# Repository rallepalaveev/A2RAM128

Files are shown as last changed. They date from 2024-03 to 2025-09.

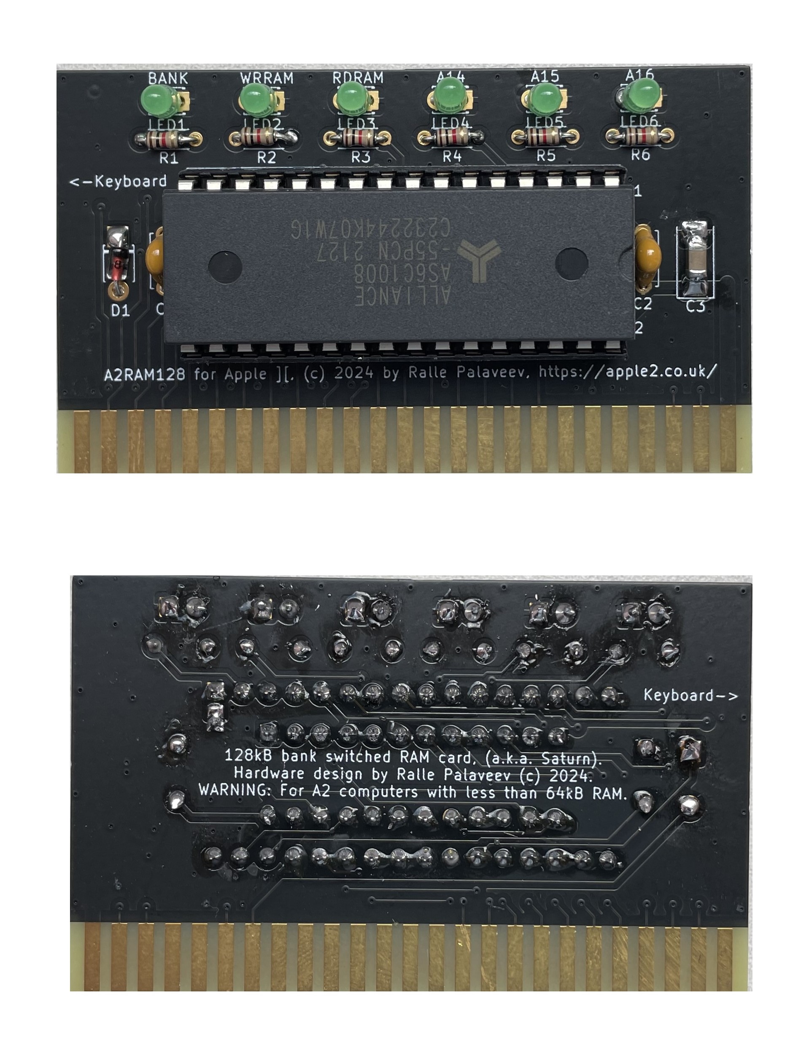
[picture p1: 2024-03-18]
A2RAM128.jpg

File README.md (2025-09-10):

# A2RAM128

This is an expansion 128kB RAM card for Apple2 computers, which uses the the upper 16kB, which are mapped to the 12kB ROM space $D000-$FFFF.

The card uses the standard 50-pin slots, and adds 8 banks of 16kB - a total of 128kB, based on modern chips like SRAM, and not needing to have any additional cables to connect to the motherboard.

This project is based on one 128kB SRAM chip and one PLD for logic.

The logic of the card follows the design recommendations of the Saturn cards:

There are 8 x 16kB banks of the following organization:
* Two sub-banks A and B of 4kB are mapped to $D000-$DFFF
* One sub-bank of 8kB is mapped to $E000-$FFFF

Bank-switched RAM soft switches:

| Address | Symbolic Name | Bank | Read From | Write to RAM? |
|:---|:---|:-----|:---|:---|
|$C0N0|READBSR2|2|RAM|No|
|$C0N1|WRITEBSR2|2|ROM|Yes*|
|$C0N2|OFFBSR2|2|ROM|No|
|$C0N3|RDWRBSR2|2|RAM|Yes*|
|$C0N8|READBSR1|1|RAM|No|
|$C0N9|WRITEBSR1|1|ROM|Yes*|
|$C0NA|OFFBSR1|1|ROM|No|
|$C0NB|RDWRBSR1|1|RAM|Yes*|

| Address | Function |
|:---|:---|
|$C0N4|Select Bank 1|
|$C0N5|Select Bank 2|
|$C0N6|Select Bank 3|
|$C0N7|Select Bank 4|
|$C0NC|Select Bank 5|
|$C0ND|Select Bank 6|
|$C0NE|Select Bank 7|
|$C0NF|Select Bank 8|

N is the Slot Number + 8.

Operation:

The card houses the 3 soft-switches above which upon reset are configured in the default configuration:

* Sub-bank A is selected
* ROM is readable
* RAM is writeable (v2.0 RAM is not writable)

A test to be made for quick check of functionality:

]CALL-151           # Enter monitor

*C0N1               # Start activation of RAM for writing (v2 only)

*C0N1               # Activation of RAM for writing

*F800<F800.FFFFM    # Copy monitor to RAM

*C0N3               # Set RAM for reading

This sequence should not lead to the computer freezing with a responce "$C0N3-", because the monitor is copied to the RAM and continues to work from RAM.

The benefit of the card is that programs which require 64kB of RAM or more can be used - primarily ProDOS. It works from any 50-pin slot with no additional cabling - P&P, however some programs expect that the card is in slot #0, so this is the recommended use.

V2.0 was created to fullfill the requrements by the Saturn cards to activate the card for writing by two succecutive calls to C0N1. It is advisable that this version is used.

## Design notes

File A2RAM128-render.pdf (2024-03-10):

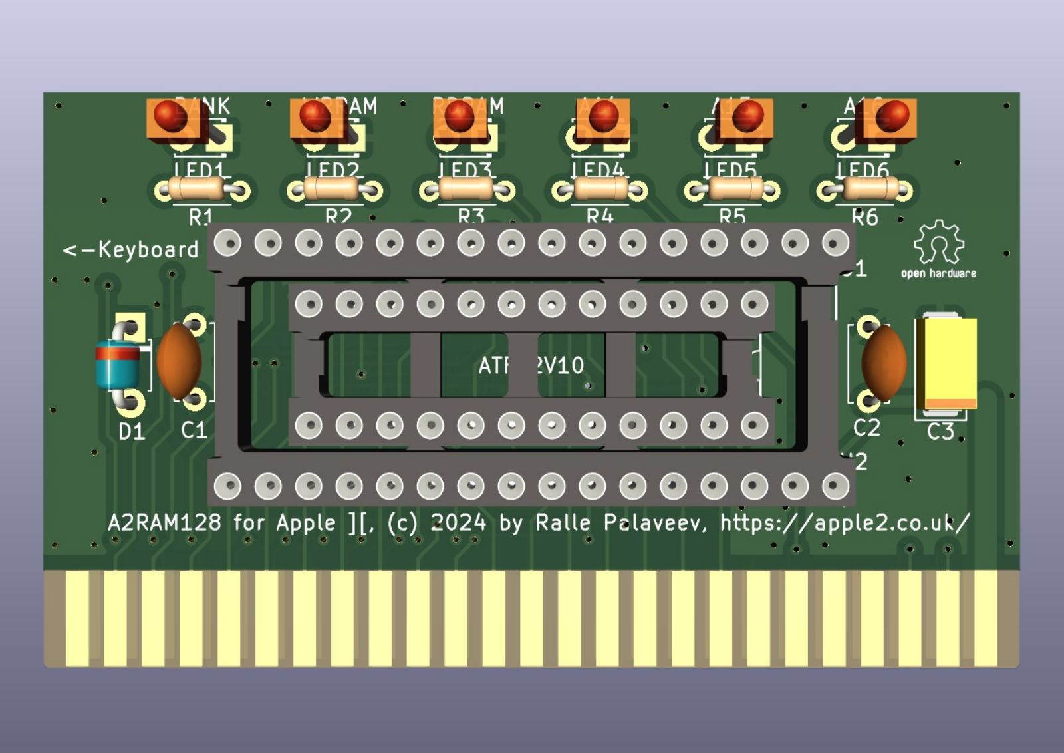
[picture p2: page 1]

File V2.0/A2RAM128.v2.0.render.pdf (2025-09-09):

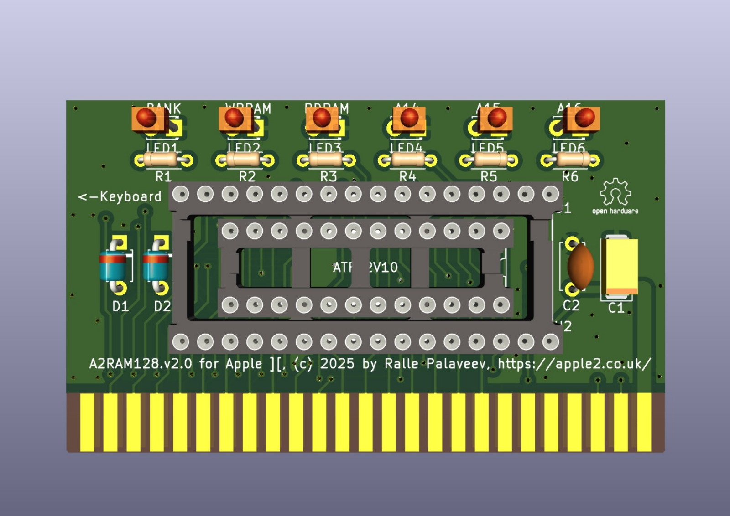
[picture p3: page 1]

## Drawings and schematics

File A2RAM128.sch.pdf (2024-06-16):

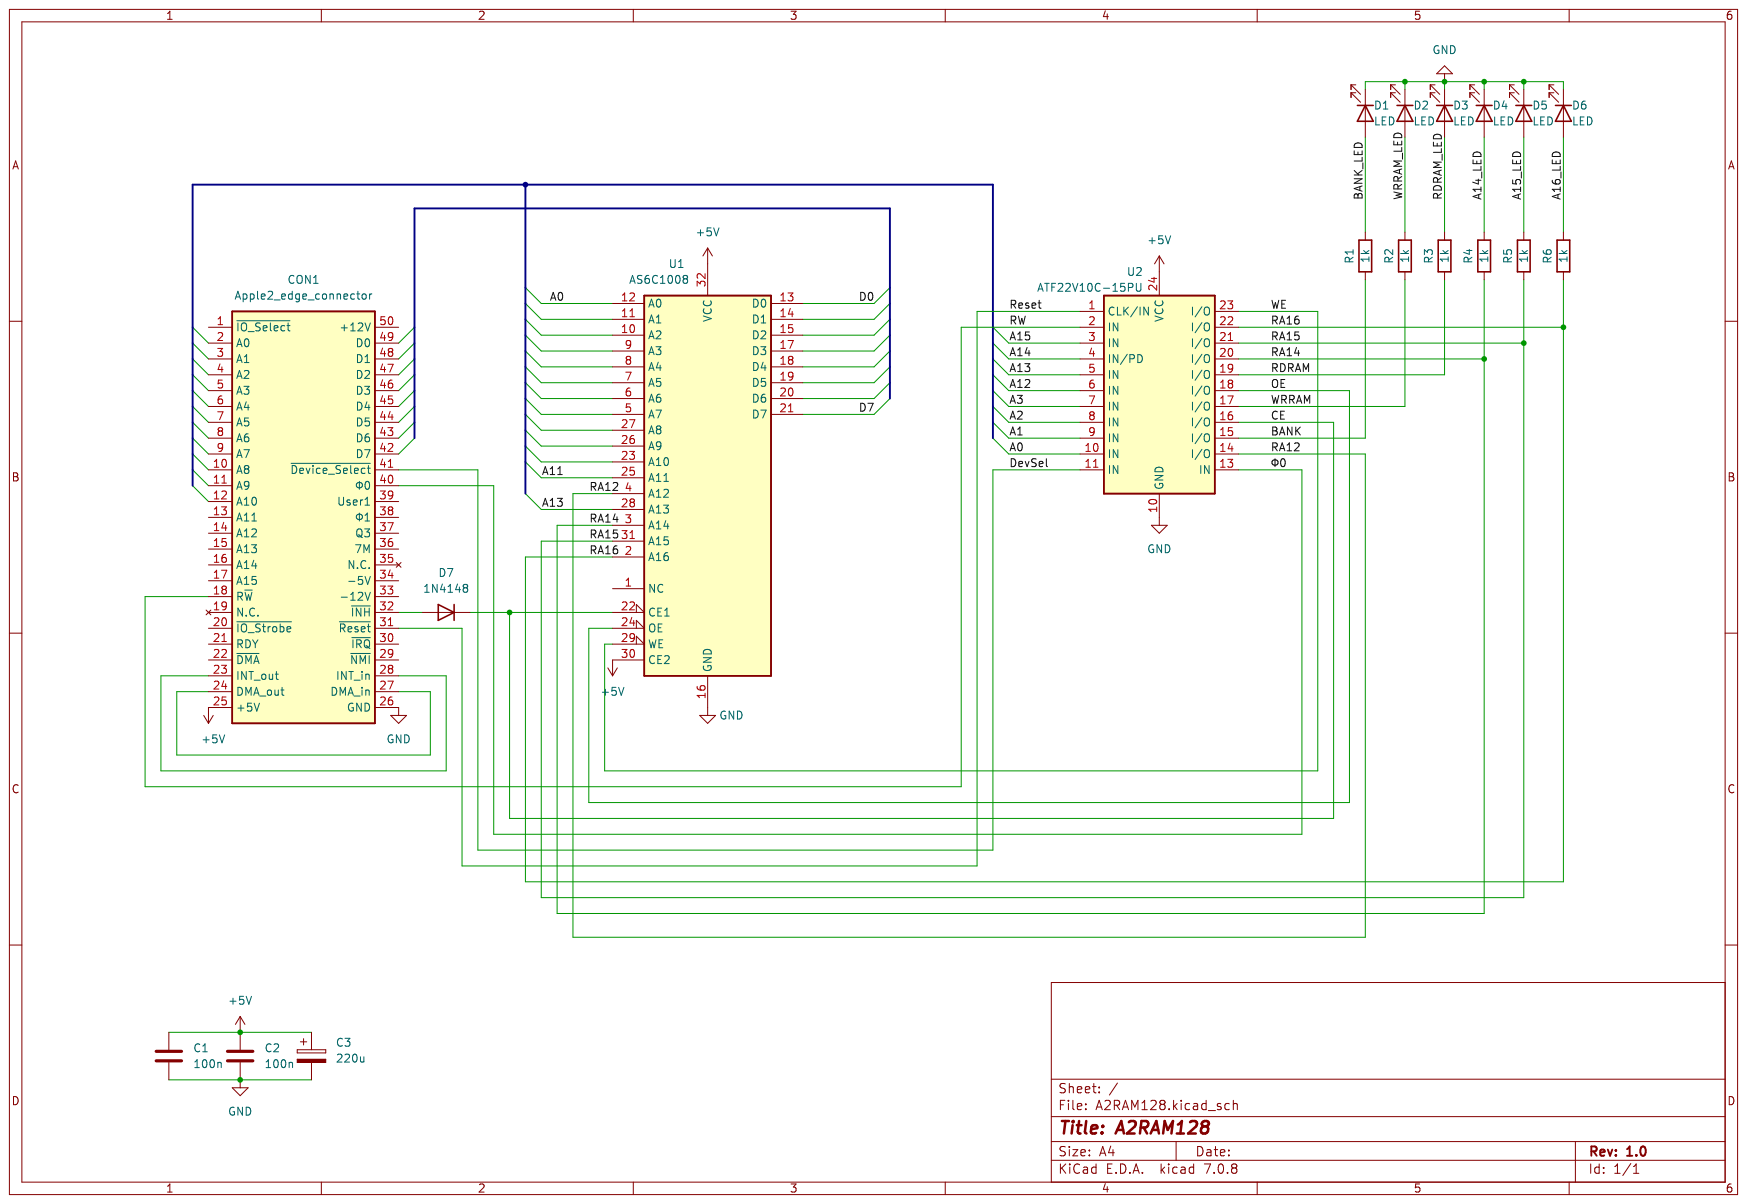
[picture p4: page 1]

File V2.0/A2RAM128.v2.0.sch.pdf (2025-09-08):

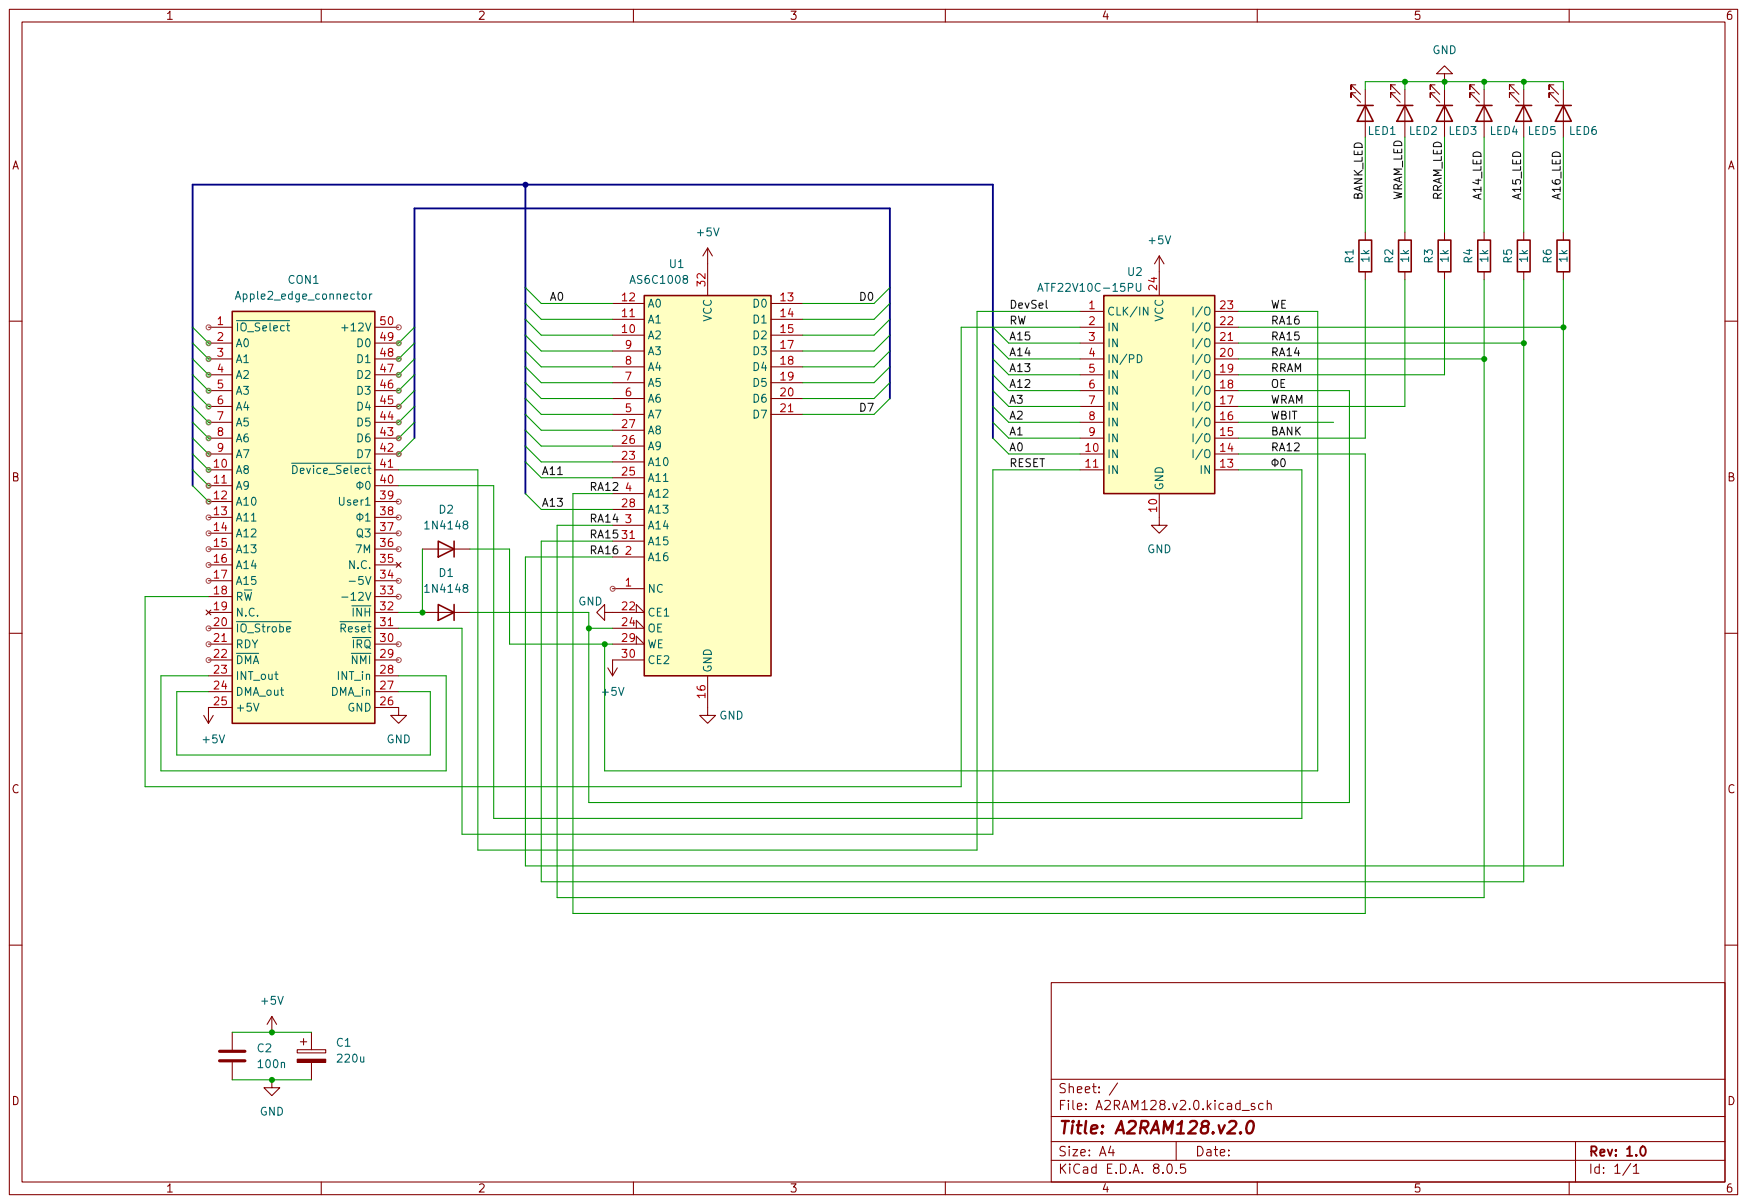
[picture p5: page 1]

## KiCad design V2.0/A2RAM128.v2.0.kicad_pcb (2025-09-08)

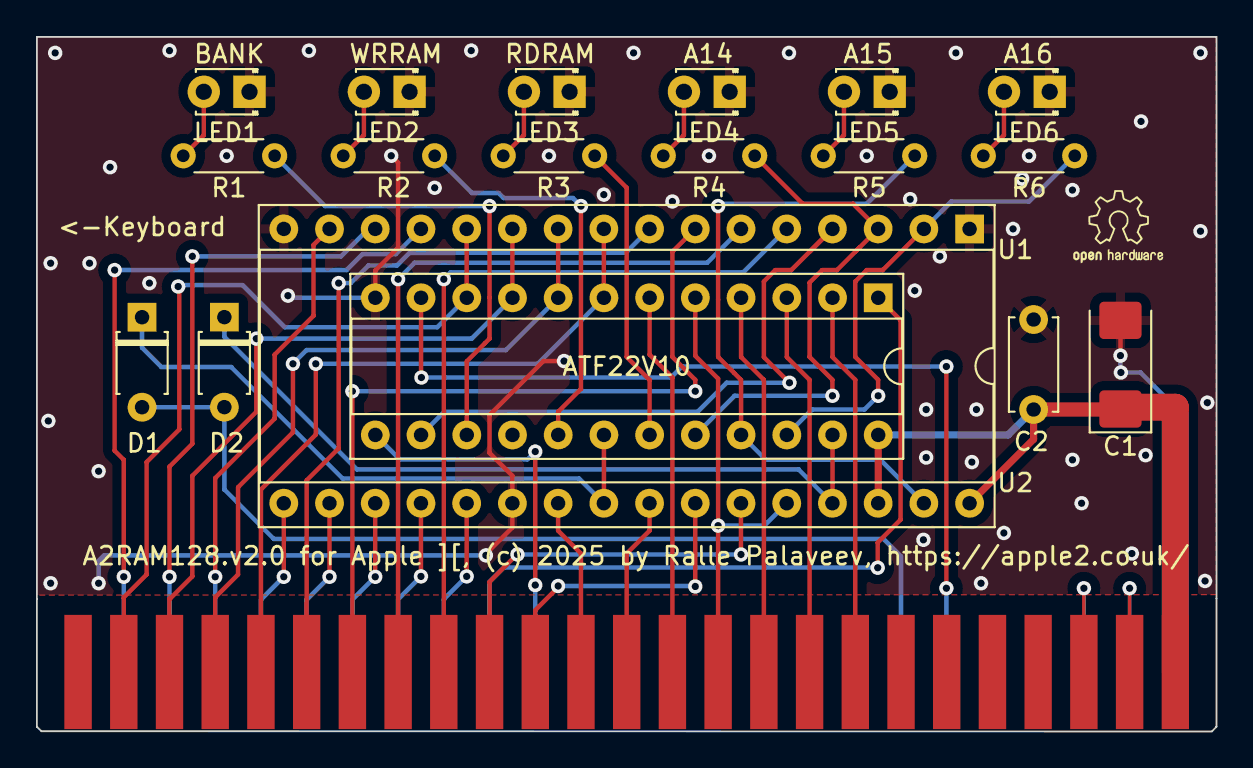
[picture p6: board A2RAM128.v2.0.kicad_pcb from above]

Board: 2 copper layers, 65.5 x 38.6 mm, 18 parts (0 on the bottom side), 17 nets.

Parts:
C1: 220uF; CP_EIA-6032-15_Kemet-U
C2: 100n; C_Disc_D5.0mm_W2.5mm_P5.00mm
D1, D2: D_T-1_P5.08mm_Horizontal
LED1, LED2, LED3, LED4, LED5, LED6: LED_D1.8mm_W3.3mm_H2.4mm
R1, R2, R3, R4, R5, R6: 1k; R_Axial_DIN0204_L3.6mm_D1.6mm_P5.08mm_Horizontal
U1: DIP-32_W15.24mm_Socket
U2: DIP-24_W7.62mm_Socket

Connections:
5V: C1.1, C2.1, U1.30, U1.32, U2.24
A0: U1.12, U2.10
A1: U1.11, U2.9
A2: U1.10, U2.8
A3: U1.9, U2.7
A13: U1.28, U2.5
BANK: R1.2, U2.15
GND: C1.2, C2.2, LED1.1, LED2.1, LED3.1, LED4.1, LED5.1, LED6.1, U1.1, U1.16, U1.22, U2.12
INH: D1.2, D2.2
OE: D1.1, U1.24, U2.18
RA12: U1.4, U2.14
RA14: R4.2, U1.3, U2.20
RA15: R5.2, U1.31, U2.21
RA16: R6.2, U1.2, U2.22
RDRAM: R3.2, U2.19
WE: D2.1, U1.29, U2.23
WRRAM: R2.2, U2.17

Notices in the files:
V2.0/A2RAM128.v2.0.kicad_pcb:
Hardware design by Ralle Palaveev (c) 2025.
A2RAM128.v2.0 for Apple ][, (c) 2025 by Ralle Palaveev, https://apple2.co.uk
